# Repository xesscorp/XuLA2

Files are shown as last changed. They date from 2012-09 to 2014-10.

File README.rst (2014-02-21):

==========================================
XuLA2 FPGA Board Repository
==========================================

----------------------------------------------------
Where you'll find *everything* XuLA2-related!
----------------------------------------------------

This repo integrates everything for the XuLA2 FPGA board into one place:

    pcb/:
        Here's where you'll find the schematic and PCB layout stored as Eagle 5 files.
        
    fmw/:
        This contains the firmware for the microcontroller that manages the XuLA2 USB interface.
        
            boot/:
                This is the boot code that manages the reflashing of the uC firmware over the USB link.
                
            user/:
                This is the code that runs during normal operations of the XuLA2 board.
                It manages the interface between the FPGA and the USB link.
                
    FPGA/:
        All the example FPGA designs for the XuLA2 are stored in here.
        (You can find others in the StickIt! repository under the subdirectories
        for the modules they support.)
        
    docs/:
        Look in here for the source of the XuLA2 manual and other supporting documentation.
        
    misc/:
        This is a random, grab-bag of stuff.

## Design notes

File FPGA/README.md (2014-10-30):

==========================================
XuLA2 FPGA Design Examples
==========================================

This directory contains example designs for all models of the XuLA2 board.

Any of the examples can be re-built using the `.xise` file in each directory along
with Xilinx ISE 14.

The following files also allow the examples to be rebuilt using `make`:

`setenv.bat`:
    This sets the PATH to include the Xilinx tools. It's only needed on Windows
    and you'll have to change it depending upon where you have your Xilinx tools
    installed.
    
`makefile`:
    Master makefile that compiles all the design examples for each XuLA2 board model.
    
`fpga_project.mk`:
    The makefile template for each design example. This file is included by the 
    makefile in each design example directory.
    
`fpga_project_rules.mk`:
    The rules for building an FPGA bitstream file from the files in the design
    example directory. This file is used by `fpga_project.mk`.

Really, Really Important Note!!!
------------------------------------------

All of these projects use the new unified library of VHDL components stored in the
[XESS VHDL_Lib repository](https://github.com/xesscorp/VHDL_Lib). If you try to compile 
these projects and you get a bunch of warnings about missing files, then you don't 
have this library installed or it's in the wrong place. Please look in the 
[VHDL_Lib README](https://github.com/xesscorp/VHDL_Lib/blob/master/README.rst) for 
instructions on how to install and use it.

FPGA Design Example Directories
------------------------------------------

`AdcSampler`:
    This example reads samples from a TI ADC108S ADC and stores them in the SDRAM.

`blinker`:
    A simple LED blinker from chapter 4 of the book "FPGAs!? Now What?".

`counter`:
    A simple 26-bit counter that is driven by a 100 MHz clock and whose bits are output
    through the prototyping header. This is a good design to check the functioning of
    the XuLA2 board. *Check the setting for the startup-clock - either JTAGCLK or CCLK -
    to make sure it complies with how you are using the XuLA2 board - either USB-connected
    or standalone.*
    
`EchoTest`:
    A simple design where the FPGA uses the HostIo communication module to receive
    characters from a PC and then echoes them back.
    
`EchoTestVerilog`:
    The same design as `EchoTest` except the top-level module is written in Verilog.

`fast_blinker`:
    The LED blinker design sped-up by using a DCM from chapter 5 of the book "FPGAs!? Now What?".

`fintf_jtag`:
    This design is used by the Python version of XSLOAD when it needs to read or write 
    the contents of the serial flash configuration memory on the XuLA2 board.

`fintf_jtag_old`:
    This design is used by GXSLOAD.EXE when it needs to read or write the contents of the
    serial flash configuration memory on the XuLA2 board.

`hcsr04_test`:
    A simple interface to test an HCSR04 ultrasonic distance measurement module.

`hostio_test`:
    This example tests the ability of the HostIo modules to pass
    data back-and-forth between the FPGA and the host PC.

`HostIoCommTest`:
    This example tests the ability of the HostIo communication module to pass
    data back-and-forth between the FPGA and the host PC.
    
`HostIoToI2cTest`:
    This example allows a host PC to talk to an I2C peripheral.
	
`ramintfc_jtag`:
    This design is used by the Python version of XSLOAD when it needs to read or write 
    the contents of the SDRAM on the XuLA2 board.

`ramintfc_jtag_old`:
    This design is used by GXSLOAD.EXE when it needs to read or write the contents of the
    SDRAM on the XuLA2 board.

`rand_test`:
    This example uses the hostio module to gather samples from a random-number generator module.
    
`RGBLed`:
    This example drives an RGB LED using three pulse-width modulators.
    
`SdcardCtrlTest`:
    This example tests the SD card controller module by having a PC write and read data blocks
    through the USB link.
    
`SdcardSfwTest`:
    This example tests an SD card by having a PC do low-level register reads and writes 
    to the card through the USB link.

`test_board_jtag`:
    This design is used by the Python version of XSTEST to test the SDRAM and report 
    the success or failure through the JTAG and USB links.

`test_board_jtag_old`:
    This design is used by GXSTEST.EXE to test the SDRAM and report the success or failure
    through the JTAG and USB links.

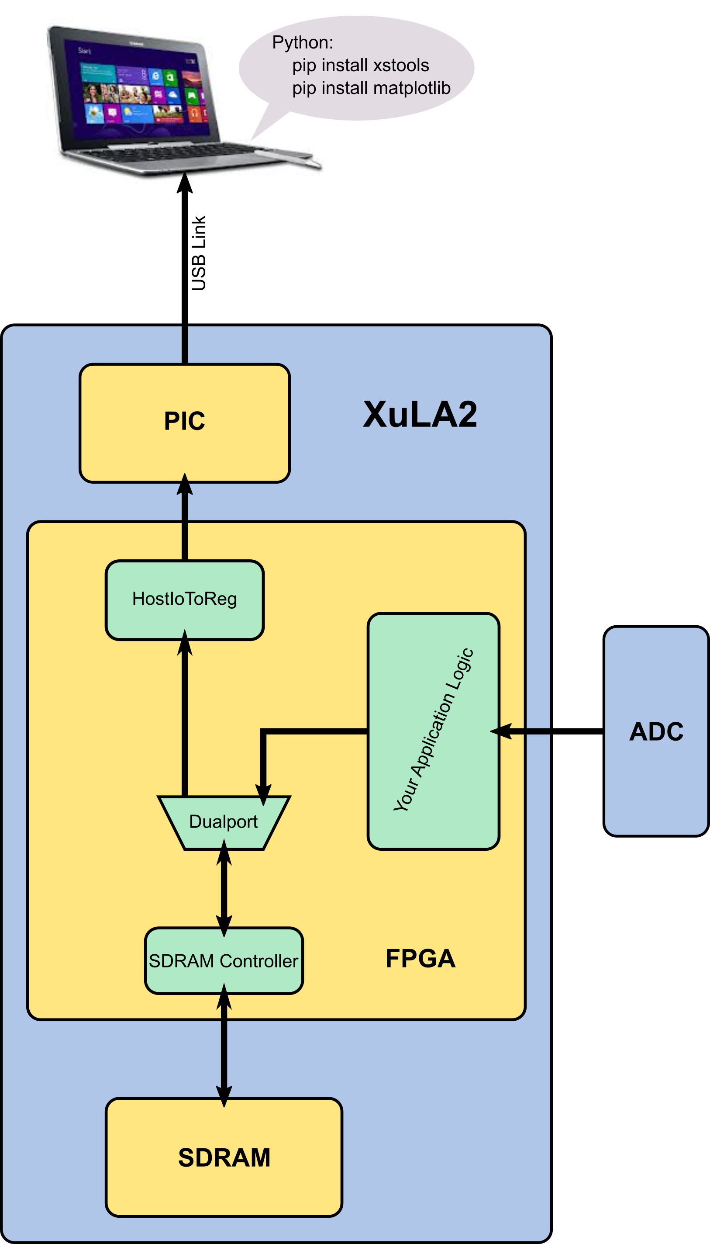
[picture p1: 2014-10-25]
FPGA/AdcSampler/AdcSampler_blockdiag.png

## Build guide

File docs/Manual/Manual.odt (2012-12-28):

How to install, test and use
your new FPGA board

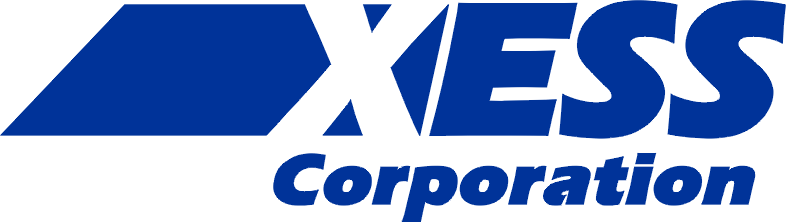
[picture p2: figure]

XESS is disclosing this Document and Intellectual Property (hereinafter “the Design”) to you for use in the development of designs to operate on, or interface with XESS hardware devices. XESS expressly disclaims any liability arising out of the application or use of the Design. XESS reserves the right to make changes, at any time, to the Design as deemed desirable in the sole discretion of XESS. XESS assumes no obligation to correct any errors contained herein or to advise you of any correction if such be made. XESS will not assume any liability for the accuracy or correctness of any engineering or technical support or assistance provided to you in connection with the Design.

THE DESIGN IS PROVIDED “AS IS” WITH ALL FAULTS, AND THE ENTIRE RISK AS TO ITS FUNCTION AND IMPLEMENTATION IS WITH YOU. YOU ACKNOWLEDGE AND AGREE THAT YOU HAVE NOT RELIED ON ANY ORAL OR WRITTEN INFORMATION OR ADVICE, WHETHER GIVEN BY XESS, OR ITS AGENTS OR EMPLOYEES. XESS MAKES NO OTHER WARRANTIES, WHETHER EXPRESS, IMPLIED, OR STATUTORY, REGARDING THE DESIGN, INCLUDING ANY WARRANTIES OF MERCHANTABILITY, FITNESS FOR A PARTICULAR PURPOSE, TITLE, AND NONINFRINGEMENT OF THIRD-PARTY RIGHTS.

IN NO EVENT WILL XESS BE LIABLE FOR ANY CONSEQUENTIAL, INDIRECT, EXEMPLARY, SPECIAL, OR INCIDENTAL DAMAGES, INCLUDING ANY LOST DATA AND LOST PROFITS, ARISING FROM OR RELATING TO YOUR USE OF THE DESIGN, EVEN IF YOU HAVE BEEN ADVISED OF THE POSSIBILITY OF SUCH DAMAGES. THE TOTAL CUMULATIVE LIABILITY OF XESS IN CONNECTION WITH YOUR USE OF THE DESIGN, WHETHER IN CONTRACT OR TORT OR OTHERWISE, WILL IN NO EVENT EXCEED THE AMOUNT OF FEES PAID BY YOU TO XESS HEREUNDER FOR USE OF THE DESIGN. YOU ACKNOWLEDGE THAT THE FEES, IF ANY, REFLECT THE ALLOCATION OF RISK SET FORTH IN THIS AGREEMENT AND THAT XESS WOULD NOT MAKE AVAILABLE THE DESIGN TO YOU WITHOUT THESE LIMITATIONS OF LIABILITY.

The Design is not designed or intended for use in the development of on-line control equipment in hazardous environments requiring fail-safe controls, such as in the operation of nuclear facilities, aircraft navigation or communications systems, air traffic control, life support, or weapons systems (“High-Risk Applications”). XESS specifically disclaims any express or implied warranties of fitness for such High-Risk Applications. You represent that use of the Design in such High-Risk Applications is fully at your risk.

© 2012 XESS, Inc. All rights reserved. XESS, the XESS logo, and other designated brands included herein are trademarks of XESS Corporation. All other trademarks are the property of their respective owners.

This document is licensed under the Attribution-ShareAlike 3.0 Unported license, available at http://creativecommons.org/licenses/by-sa/3.0/.

MAN007 (V1.2) December 28, 2012

The following table shows the revision history for this document.

Date | Version | Revision
07/25/2012 | 0.1 | Pre-release for the XuLA2.
08/1/2012 | 0.2 | Corrected “Spartan-3A” to “Spartan-6”.
08/14/2012 | 1.0 | Changed images for XuLA2 production board. Added instructions for setting FPGA bitstream configuration rate.
08/20/2012 | 1.1 | Added notes about connections from the prototyping header pins to FPGA global clock pins in the Pin Connections appendix.
12/28/2012 | 1.2 | Expanded explanation of how to use a XILINX programming cable with the XuLA2.

# Preliminaries

Here's some helpful information before getting started.

## Getting Help!

Here are some places to get help if you encounter problems:

- If you can't get the XuLA2 hardware to work, send an e-mail message describing your problem to help@xess.com or submit a problem report at http://www.xess.com/help.php. Our web site also has:
  - answers to frequently-asked-questions,
  - example designs, application notes and tutorials for our FPGA boards,
  - a place to sign-up for our email forum where you can post questions to others.
- If you can't get your XILINX ISE WebPACK software tools installed properly, check their web site at http://www.xilinx.com/support/.
- If you need help using the XILINX ISE WebPACK software to create FPGA designs, then check out this tutorial (http://www.xess.com/appnotes/FpgasNowWhatBook.pdf).

## Take Notice!

- The XuLA2 is not 5V-tolerant. Do not connect 5V logic signals to the prototyping header.
- The XuLA2 printed circuit board (PCB) is manufactured such that the terminals of the jumpers labeled "5V", "3.3V" and "1.2V" are connected on the underside of the PCB by short wiring traces. You must cut these traces if you want to open the jumper connections.
- Even if you have experience with the XILINX ISE WebPACK software, please read this section on setting the bitstream generation options for the XuLA2.

# Installation

## Installing the XSTOOLs Utilities and Documentation

XILINX currently provides the free ISE® WebPACKTM software for programming many of their small and mid-size FPGAs and CPLDs. You can download the most current version of ISE WebPACK from www.xilinx.com.

In addition, XESS provides the XSTOOLs utilities for interfacing a PC to your XuLA2. These utilities (along with manuals, design examples and tutorials) are installed automatically when you insert the XSTOOLs CD into your PC. If not, then manually run the SETUP.EXE installation program on the CD. You can also download the XSTOOLs installer from www.xess.com.

## Connecting Your XuLA2 to a PC

The XuLA2 is a USB peripheral that you can attach to any USB 1.1 or 2.0 port through a cable with a five-pin mini-B connector such as this one:

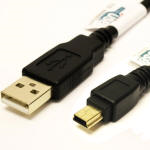
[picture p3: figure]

The LED on your XuLA2 will light up as soon as it establishes a connection with the PC.

## Testing Your XuLA2

Once your XuLA2 is connected to a USB port, you can test it by double-clicking the GXSTEST icon placed on your PC desktop during the XSTOOLs installation. This brings up the window shown below.

Next, select the type of board you are testing and the port that it's attached to. Then click on the TEST button. GXSTEST will configure the FPGA on your XuLA2 to perform a test procedure. Within a few seconds, a status window will appear informing you of the success or failure of the test.

If your XuLA2 fails the test, you will be shown a checklist of common causes for failure. If none of these applies to your situation, then contact XESS Corp (http://www.xess.com/help.php) for further assistance.

## Setting the Jumpers on Your XuLA2

The XuLA2 has three jumpers labeled "5V", "3.3V" and "1.2V" that are used to configure how the board receives power. In their factory-original configuration, the jumpers are unpopulated but the terminals of each jumper are connected on the underside of the PCB by short wiring traces. You must cut these traces if you wish to open the jumper connections. You only need to do this if you are powering your XuLA2 through its prototyping header (not through the USB cable) as described here.

The locations of the shorting traces on the underside of the XuLA2 PCB are shown below.

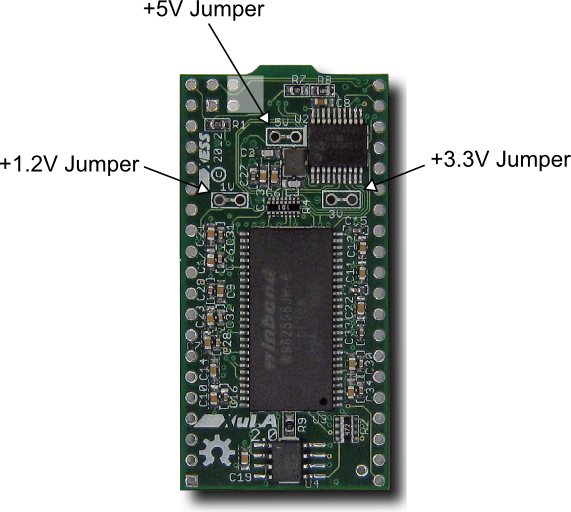
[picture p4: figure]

## Applying Power to Your XuLA2

There are two ways of powering your XuLA2 that can be used alone or in combination:

- receiving power through the USB connector, or
- applying power through the XuLA2 prototyping header.

### Applying Power Through the USB Port

Connecting the XuLA2 to a PC USB port provides a 5V supply capable of delivering up to 500 mA of current. This is sufficient for many small to medium-sized FPGA designs running at less than 200 Mhz.

### Applying Power Through the Prototyping Header

For more power-hungry applications, you can connect one or more voltage supplies directly to the power supply pins of the prototyping header. There are several ways to do this:

- You can attach an 18V–5V supply directly to the 5V pin of the prototyping header. The XuLA2's voltage regulators will generate the required 3.3V and 1.2V supplies needed by the microcontroller, FPGA, SDRAM and Flash (see the figure below). Do not attach a USB cable unless you have removed the shunt from the 5V jumper or else you will short the PC USB supply to the external voltage supply and cause possible damage.
- You can attach a 3.3V supply directly to the 3.3V pin of the prototyping header. This supply will directly power the microcontroller, FPGA I/O, SDRAM and Flash while the voltage regulator will generate the 1.2V needed by the FPGA core logic. Do not attach a USB cable unless you have removed the shunt from the 5V jumper and do not attach a supply to the 5V prototyping pin or else the output of the 3.3V regulator will drive against the external 3.3V supply and cause possible damage.
- You can power the FPGA core logic by attaching a 1.2V supply directly to the 1.2V pin of the prototyping header and then use one of the previous two methods to power the rest of the XuLA2. You must remove the shunt on the 1.2V jumper to isolate the output of the 1.2V regulator from the external 1.2V supply.

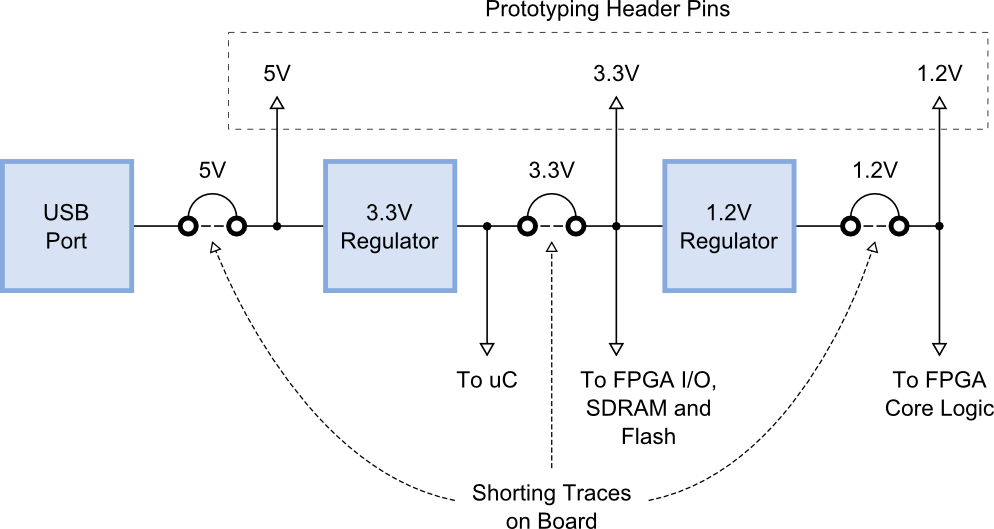
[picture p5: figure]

## Inserting the XuLA2 into a Breadboard

In its factory-original configuration, the XuLA2's prototyping header is empty. If desired, you can solder in a pair of twenty-pin headers and then insert the XuLA2 into a standard solderless breadboard as shown below.

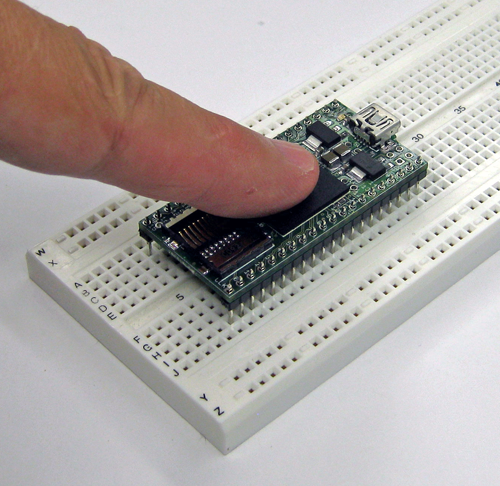
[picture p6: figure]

The XuLA2 PCB will accept common headers with 0.025"-thick pins at 0.1" spacing, but you may find it difficult to remove the XuLA2 given how tightly the breadboard grips the pins. A header with thinner pins (such as the Aries 20-0600-20) is a better choice.

# Programming

This chapter will show you how to download logic designs into the FPGA of your XuLA2 and how to transfer data between the PC and the SDRAM and Flash memories on the board.

## Generating Bitstreams for the FPGA

Before you can download a logic design to the FPGA on your XuLA2, you need to generate a bitstream (i.e., a .BIT file) with XILINX ISE WebPACK. Steps for doing this are given in the XILINX documentation and this XESS tutorial (http://www.xess.com/appnotes/FpgasNowWhatBook.pdf), but there are several details that you have to be aware of when generating the bitstream.

After creating your logic design in ISE WebPACK, right-click on the Generate Programming File item in the Process window and select Process Properties... from the context menu as shown below.

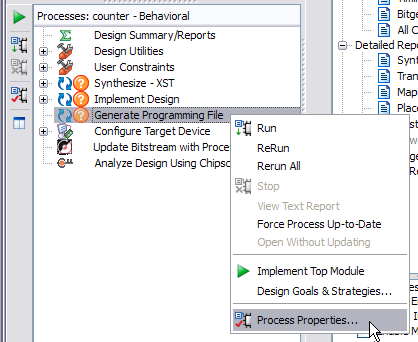
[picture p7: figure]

When the Process Properties window appears, select the Configuration Options category. Make sure the Configuration Pin Done property is set to the value Pull Up. This is necessary for the microcontroller on the XuLA2 to detect when the FPGA has successfully been configured by the bitstream. Also, set the JTAG Pin TCK property to either Float or Pull Down so it does not conflict with the pull-down resistor on the XuLA2. Finally, set the Unused IOB Pins property Float or Pull Up.

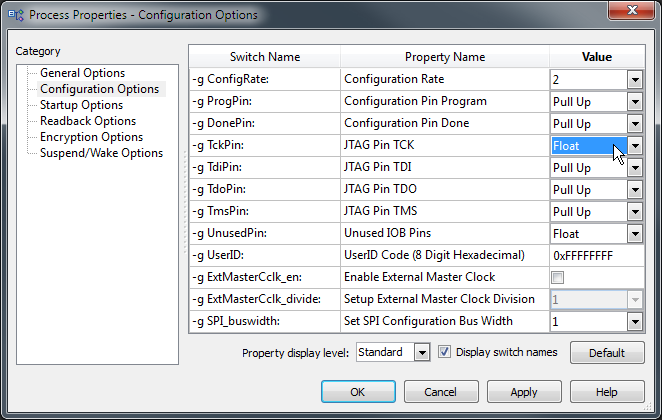
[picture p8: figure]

If you're planning on storing the bitstream into the serial configuration flash, you will also want to set the Configuration Rate to 10 MHz or more. That will ensure the 5 Mbit bitstream will load into the FPGA in ½-second or less. But if you're only going to download the bitstream to the FPGA via the USB link, then the Configuration Rate setting can be ignored.

Finally, select the Startup Options category and set the FPGA Start-Up Clock to one of the following values:

FPGA Start-Up Clock Settings
JTAG Clock | Use this setting when your bitstream will be downloaded directly into the XuLA2's FPGA through the USB cable.
CCLK | Use this setting when your bitstream will be downloaded into the XuLA2's serial configuration Flash for eventual transfer to the FPGA.

Then click OK to finalize your process properties. Now you're ready to generate a bitstream for the XuLA2!

## Downloading Bitstreams into the FPGA

### Downloading Using GXSLOAD

As you work on a logic design, you will usually download the bitstream from the PC to the XuLA2 to test your modifications. The GXSLOAD utility is used for downloading bitstreams over the USB link.

Start GXSLOAD by double-clicking the icon placed on the desktop during the XSTOOLs installation. This brings up the window shown below.

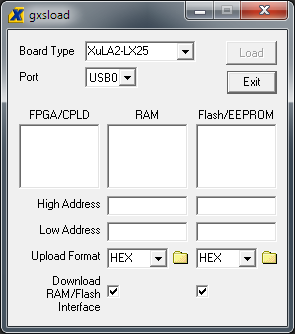
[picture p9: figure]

Now you can download bitstream files to the FPGA or CPLD simply by dragging them from their folder and dropping them into the FPGA/CPLD pane as shown below.

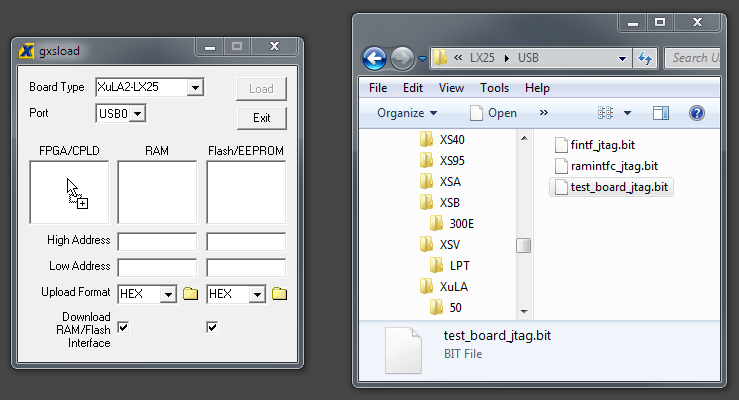
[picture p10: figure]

Once you drop the file, the highlighted file name appears in the FPGA/CPLD pane and the Load button is enabled. Clicking on the Load button will begin sending the bitstream to the XuLA2 through the USB cable. GXSLOAD will reject any non-downloadable files (ones with a suffix other than .BIT). During the downloading process, GXSLOAD will display the name of the bitstream file and the progress of the current download. The LED on the XuLA2 will blink as the bitstream is transferred.

You can drag & drop multiple files into the FPGA/CPLD pane. Clicking your mouse on a file name will highlight the name and select it for downloading. Only one file at a time can be selected for downloading.

Double-clicking the highlighted file will deselect it so no file will be downloaded. Doing this disables the Load button.

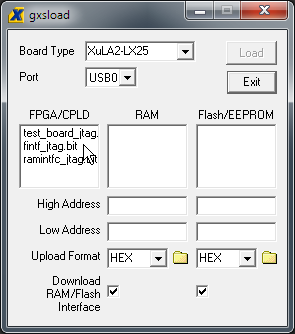
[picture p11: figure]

### Downloading Using a XILINX or Third-Party JTAG Cable

As an alternative to using GXSLOAD and a simple USB cable, you can use a XILINX or third-party JTAG cable to configure the FPGA on the XuLA2. But first, you have to set a non-volatile flag to give priority to the auxiliary JTAG header using the GXSFLAGS utility. Connect the XuLA to your PC with a USB cable and then double-click the GXSFLAGS icon so the following window appears.

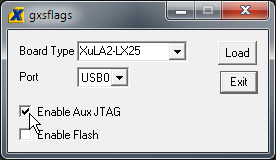
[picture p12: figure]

Click on the Enable Aux JTAG checkbox and then click on the Load button to set the flag. Note that the flag only needs to be set once to support the JTAG cable because it retains its value even when power is removed from the XuLA2. (Be aware that enabling the auxiliary JTAG header disables the functions of the other XSTOOLs utilities such as GXSTEST and GXSLOAD. To restore their functions, you'll have to use GXSFLAGS again to disable the auxiliary JTAG header.)

Now attach your JTAG cable to the auxiliary JTAG header as shown below. (The USB cable remains attached only to provide the XuLA2 with power. You can detach it if the board is getting power from another source, such as through its prototyping header.)

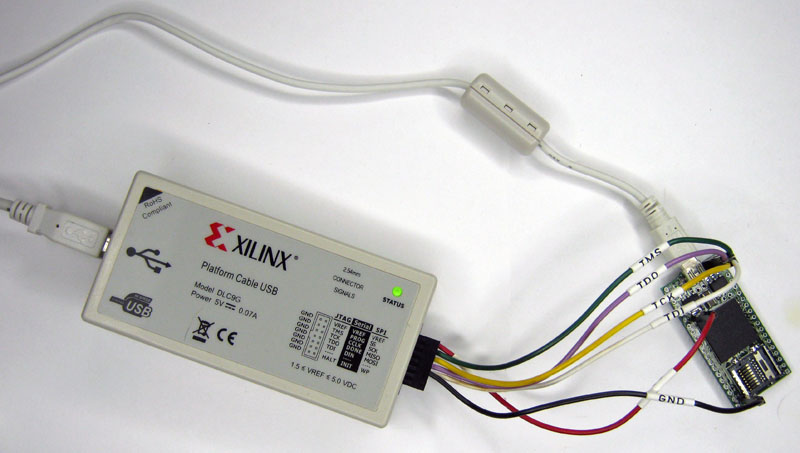
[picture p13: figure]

Here's a close-up of the connections from the XILINX cable to the XuLA2:

Ground Connection Vref Connection To +3.3V JTAG Signal Connections

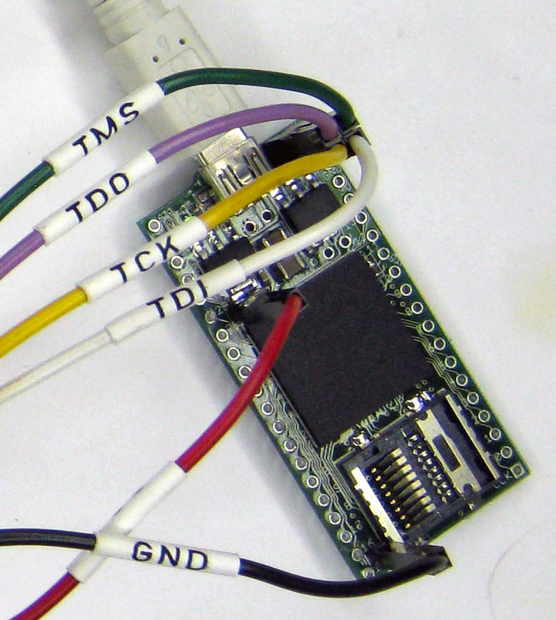
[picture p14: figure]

Now start the ISE WebPACK iMPACT tool and follow the XILINX instructions to download bitstreams to the FPGA in boundary-scan mode.

## Storing Non-Volatile Bitstreams in the Serial Configuration Flash

The FPGA on the XuLA2 stores its configuration in an on-chip SRAM which is erased whenever power is removed. Once you complete a design, you may want to store the bitstream in the serial configuration Flash on the XuLA2. After that, the FPGA will configure itself from the Flash each time power is applied.

Loading a bitstream into the Flash is easy: just drag the .BIT file into the Flash/EEPROM pane of GXSLOAD and click on the Load button. This activates the following sequence of events:

1. The FPGA on the XuLA2 is configured with an interface to transfer data from the USB port to the Flash.
2. The entire Flash is erased.
3. The contents of the .BIT file are downloaded into the Flash through the USB port.

Once the Flash download is completed, the FPGA will be configured with the stored bitstream whenever power is applied to the XuLA2. (Make sure that you selected CCLK as the start-up clock and set the configuration rate to 10 MHz or more when you generated the bitstream or else the FPGA will fail to configure from the Flash.)

You can also use the XILINX iMPACT software to convert FPGA bitstreams into .MCS or .EXO data files. These file types can be programmed into the XuLA2's Flash using GXSLOAD in the same way as with a .BIT file.

Multiple files can be stored in the Flash device just by dragging them into the Flash/EEPROM area, highlighting the files to be downloaded and clicking the Load button. (Note that anything previously stored in the Flash will be erased by each new download.) This is useful if you need to store information in the Flash in addition to the FPGA bitstream. Files are selected and de-selected for downloading just by clicking on their names in the Flash/EEPROM area. The address ranges of the data in each file should not overlap or this will corrupt the data stored in the Flash device!

You can also examine the contents of the Flash by uploading it to the PC. To upload data from an address range in the Flash, type the upper and lower bounds of the range into the High Address and Low Address fields located below the Flash/EEPROM pane, and select the format for the uploaded data from the Upload Format pulldown list. Then click on the file icon () and drag & drop it into any folder.

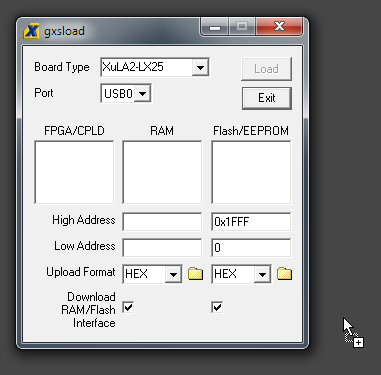
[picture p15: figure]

This activates the following sequence of steps:

1. The FPGA on the XuLA2 is configured with an interface between the Flash device and the PC USB port.
2. The Flash data between the high and low addresses (inclusive) is uploaded through the USB port.
3. The uploaded data is stored in a file named FLSHUPLD with an extension that reflects the selected upload file format.

The uploaded data can be stored in the following formats:

MCS: Intel hexadecimal file format.

HEX: Identical to MCS format.

EXO-16: Motorola S-record format with 16-bit addresses (suitable for 64 KByte uploads only).

EXO-24: Motorola S-record format with 24-bit addresses.

EXO-32: Motorola S-record format with 32-bit addresses.

XESS-16: XESS hexadecimal format with 16-bit addresses. (This is a simplified file format that does not use checksums.)

XESS-24: XESS hexadecimal format with 24-bit addresses.

XESS-32: XESS hexadecimal format with 32-bit addresses.

## Transferring Data to/from the SDRAM

The XuLA2 contains a synchronous DRAM (SDRAM) whose contents can be downloaded and uploaded by GXSLOAD. This is useful for initializing the SDRAM with data for use by the FPGA and then reading the SDRAM contents after the FPGA has operated upon it. The SDRAM is loaded with data by dragging & dropping one or more .EXO, .MCS, .HEX, and/or .XES files into the RAM pane of the gxsload window and then clicking on the Load button. This activates the following sequence of steps:

1. The FPGA is configured with an interface to transfer data between the SDRAM device and the USB port.
2. The contents of the .EXO, .MCS, .HEX or .XES file are downloaded into the SDRAM through the USB port.

You can also examine the contents of the SDRAM device by uploading it to the PC. To upload data from an address range in the SDRAM, type the upper and lower bounds of the range into the High Address and Low Address fields below the RAM pane, and select the format for the uploaded data from the Upload Format pulldown list. Then click on the file icon () and drag & drop it into any folder.

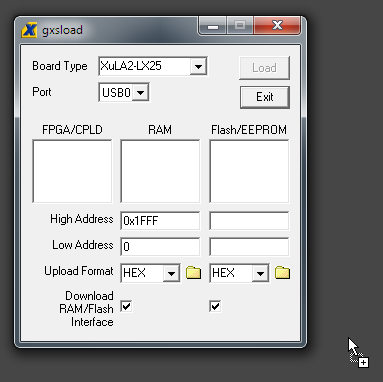
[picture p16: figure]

This activates the following sequence of steps:

1. The FPGA is configured with an interface between the SDRAM device and the PC USB port.
2. The SDRAM data between the high and low addresses (inclusive) is uploaded through the USB port.
3. The uploaded data is stored in a file named RAMUPLD with an extension that reflects the selected upload file format.

The 16-bit data words in the SDRAM are mapped into the eight-bit data format of the .HEX, .MCS, .EXO and .XES files using a Big Endian style. That is, the 16-bit word at location N in the SDRAM is stored in the eight-bit file with the upper eight bits at address 2N and the lower eight bits at address 2N+1. This byte-ordering applies for both RAM uploads and downloads.

# Programmer Models

This section describes the various sections of the XuLA2 and shows how the FPGA I/O is connected to the rest of the circuitry. The schematics which follow are less detailed so as to simplify the descriptions. For more information, you can find a table of pin connections and detailed schematics at the end of this manual.

## XuLA2 Components

The XuLA2 contains the following major components:

FPGA: This is the field programmable gate array.

Microcontroller: The microcontroller (uC) handles initialization, clock generation and USB-to-JTAG communications.

SDRAM: A 256-Mbit SDRAM provides volatile data storage accessible by the FPGA.

SPI Flash: An 8-Mbit serial Flash device provides non-volatile storage for FPGA configuration bitstreams and user data.

MicroSD Card: A Secure Digital memory card provides non-volatile storage for user data.

Prototyping Header: FPGA I/O pins, several uC pins and power/GND pins are connected to this 40-pin header that is meant to mate with solderless breadboards or other devices with 0.1"-spacing sockets.

Aux. JTAG Header: This header provides direct access to the FPGA's JTAG pins.

The interconnection of these components is shown in the following block diagram.

### FPGA

The programmable logic device on the XuLA2 is a XILINX XC6SLX25 Spartan 6 FPGA (http://www.xilinx.com/support/documentation/data_sheets/ds160.pdf) in a 256-ball BGA package (FT256).

### Microcontroller

The XuLA2 uses a Microchip 18F14K50 PIC (http://www.microchip.com/wwwproducts/Devices.aspx?dDocName=en533924) to perform the following functions:

Reset & initialization: Upon power-up or assertion of the reset, the microcontroller initiates the configuration of the FPGA from the SPI Flash and holds the FPGA in its cleared state if the configuration fails. It instantiates its USB endpoints and participates in the USB enumeration process.

Clock generation: The microcontroller uses its pulse-width modulation (PWM) circuitry to generate a 12 MHz square-wave that enters one of the FPGA's global clock inputs.

USB-to-JTAG communication: The microcontroller accepts configuration bitstreams and data as packets over the USB link and transforms these into a sequence of transitions upon the FPGA's JTAG pins. It also receives data from the FPGA through the JTAG port which it bundles into packets for return through the USB link.

### SDRAM

The XuLA2 incorporates a 16M x 16 SDRAM (Winbond W9825G6JH (http://www.winbond.com/hq/enu/ProductAndSales/ProductLines/SpecialtyDRAM/SDRAM/W9825G6JH.htm)) that connects to the FPGA as shown below. To compensate for circuit delays, the clock signal to the SDRAM is re-routed back to a global clock input so the FPGA can synchronize itself with the SDRAM.

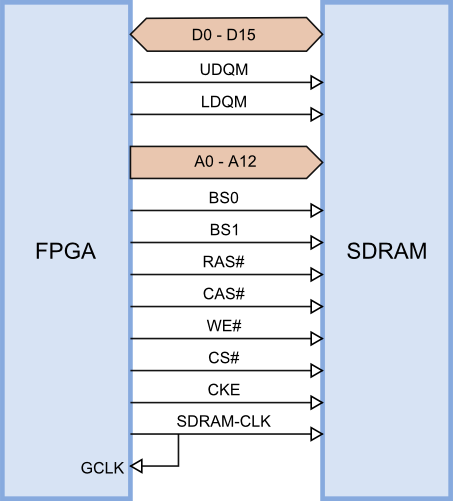
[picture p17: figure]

### SPI Flash and microSD Card

The XuLA2 has an 8-Mbit SPI Flash (Winbond W25Q80BV (http://www.winbond.com/hq/enu/ProductAndSales/ProductLines/FlashMemory/SerialFlash/W25Q80BV.htm)) and a microSD card socket that connect to the FPGA as shown below. During FPGA configuration, the bitstream is read from the SPI flash while the microSD card is disabled. After configuration, either the SPI Flash or the microSD card can be accessed by lowering their respective chip-selects and performing SPI read/write operations.

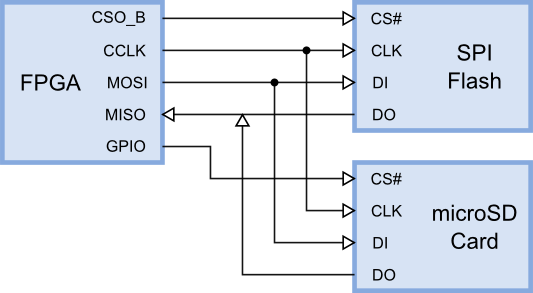
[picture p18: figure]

### Prototyping Header

The prototyping header connects the FPGA I/O, microcontroller I/O and the power/GND planes to external circuitry. The signals attached to the header pins are shown below.

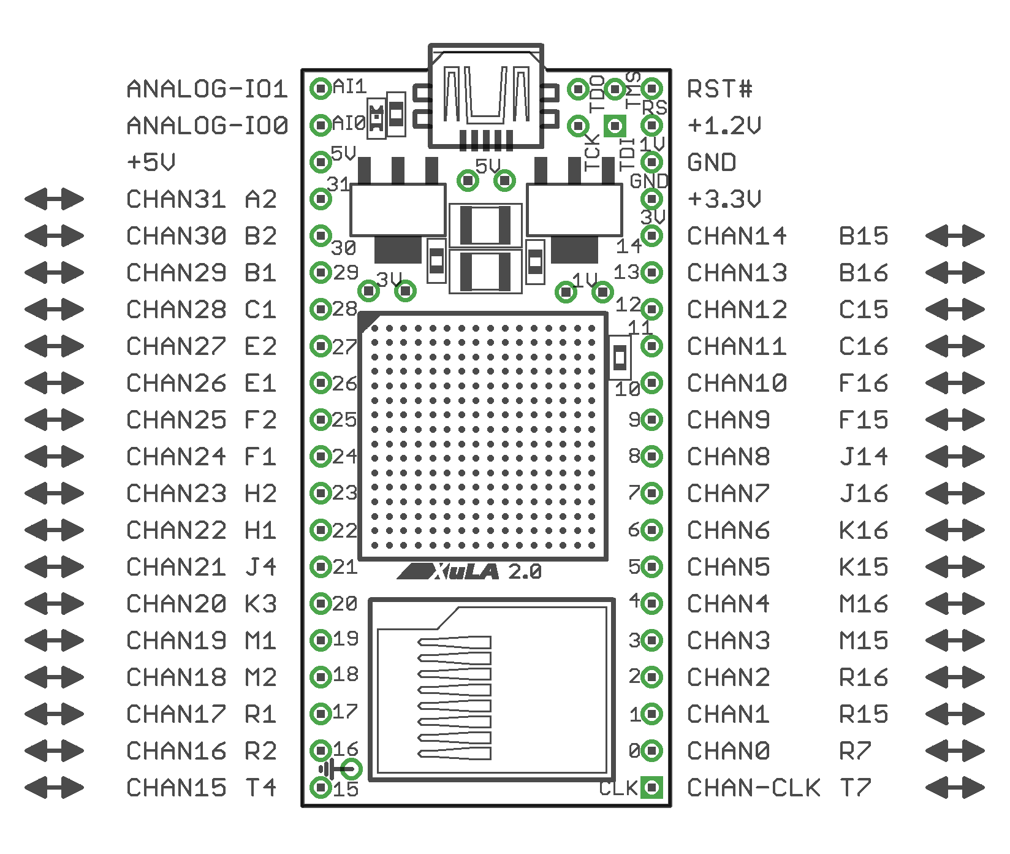
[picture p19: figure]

XuLA2 Header Pin Functions
CHAN0 – CHAN31 | These pins connect directly to the FPGA I/O pins. These pins are not 5V-tolerant (see below).
CHAN-CLK | This is a direct connection to a global clock pin of the FPGA. It can also be used as a general-purpose I/O pin. This pin is not 5V-tolerant (see below).
+5V, +1.2V, +3.3V, GND | These pins connect to the voltage supply planes of the XuLA2 as depicted in this figure.
RST# | This pin connects to the microcontroller reset pin. Pulling it to ground and releasing it will cause the XuLA2 to reconfigure itself.
ANALOG-IO0, ANALOG-IO1 | These pins connect to the analog-to-digital converter in the microcontroller. ANALOG-IO0 can also output an analog voltage with a limited range and precision. Both pins are also useable as standard digital I/O pins.

#### 5V Tolerance Issues

The CHAN* and CHAN-CLK pins connect directly to the pins of the FPGA which typically use an I/O voltage of 3.3V. When driving the inputs of external 5V logic, you should check that their VIH threshold is less than the VOH of the XuLA2 outputs. (This is true for most 5V logic families.)

You must also take care not to exceed the input voltage rating of the FPGA pins when they are driven by external 5V logic outputs. A common technique for protecting the Xilinx FPGA pins is shown below. When presented with a voltage greater than 3.3V + 0.7V = 4.0V, the protection diode built into the FPGA pin's circuitry conducts current and the excess voltage is dropped across the 100Ω resistor. This keeps the voltage directly on the FPGA pin from ever exceeding 4V, which is within tolerated limits. The resistor value should be set so the current through the protection diode does not exceed 10 mA.

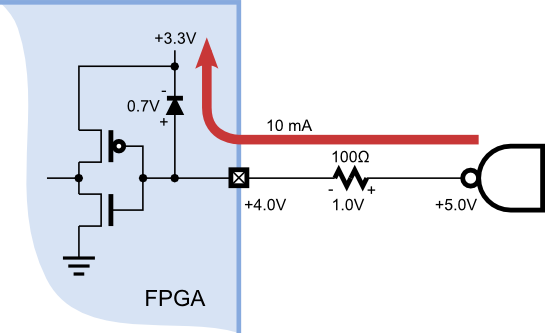
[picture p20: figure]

However, by default, the Xilinx Spartan-6 FPGA disables the protection diodes. In order to enable these diodes, you can place the following text into your Xilinx ISE project constraint file for every I/O pin that will be connected to 5V logic:

NET "input_name" IOSTANDARD = PCI66_3;

Or you can use the Xilinx PlanAhead tool to set the I/O standard for the pins like so:

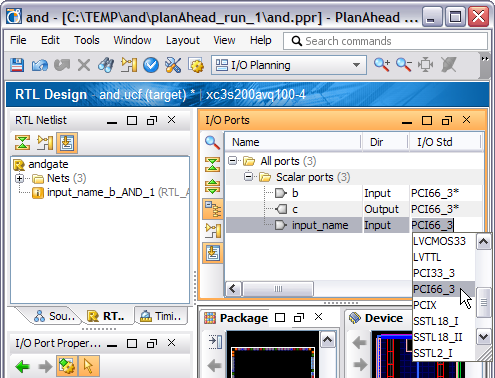
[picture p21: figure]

### Auxiliary JTAG Header

This four-pin header (shown below) provides third-party JTAG cables with access to the JTAG pins of the FPGA.

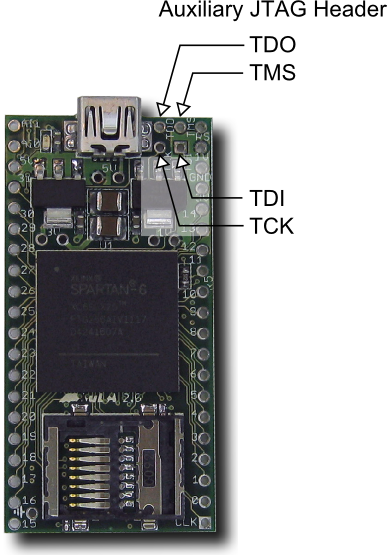
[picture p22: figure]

The connections of the JTAG header to the rest of the XuLA2 circuitry are as follows.

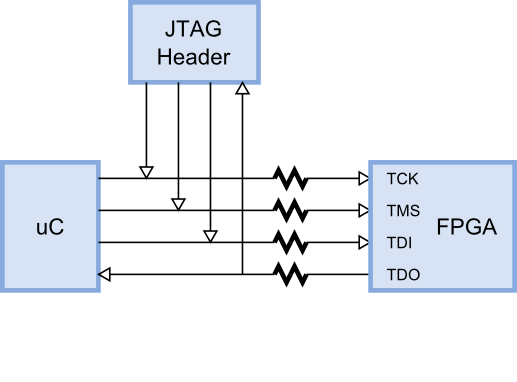
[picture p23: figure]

The current limiting resistors prevent the microcontroller or JTAG cable from damaging the FPGA if they are using a higher supply voltage than the FPGA.

When using a third-party JTAG cable, the associated I/O pins of the microcontroller must be placed in a high-impedance state. The procedure for doing this is described here.

# Pin Connections

Net Name | FPGA | SDRAM | Prototyping Header | SPI Flash | microSD | uC | Notes
A0 | E4 | A0
A1 | E3 | A1
A2 | D3 | A2
A3 | C3 | A3
A4 | B12 | A4
A5 | A12 | A5
A6 | D12 | A6
A7 | E12 | A7
A8 | G16 | A8
A9 | G12 | A9
A10 | F4 | A10
A11 | G11 | A11
A12 | H13 | A12
BS0 | H3 | BS0
BS1 | G3 | BS1
CAS# | L3 | CAS#
CHAN-CLK | T7 | | CHAN-CLK | | | | Goes to FPGA GCLK pin.
CHAN0 | R7 | | CHAN0 | | | | Goes to FPGA GCLK pin.
CHAN1 | R15 | | CHAN1
CHAN2 | R16 | | CHAN2
CHAN3 | M15 | | CHAN3
CHAN4 | M16 | | CHAN4
CHAN5 | K15 | | CHAN5
CHAN6 | K16 | | CHAN6
CHAN7 | J16 | | CHAN7 | | | | Goes to FPGA GCLK pin.
CHAN8 | J14 | | CHAN8 | | | | Goes to FPGA GCLK pin.
CHAN9 | F15 | | CHAN9
CHAN10 | F16 | | CHAN10
CHAN11 | C16 | | CHAN11
CHAN12 | C15 | | CHAN12
CHAN13 | B16 | | CHAN13
CHAN14 | B15 | | CHAN14
CHAN15 | T4 | | CHAN15
CHAN16 | R2 | | CHAN16
CHAN17 | R1 | | CHAN17
CHAN18 | M2 | | CHAN18
CHAN19 | M1 | | CHAN19
CHAN20 | K3 | | CHAN20 | | | | Goes to FPGA GCLK pin.
CHAN21 | J4 | | CHAN21 | | | | Goes to FPGA GCLK pin.
CHAN22 | H1 | | CHAN22
CHAN23 | H2 | | CHAN23
CHAN24 | F1 | | CHAN24 | | | | Goes to FPGA GCLK pin.
CHAN25 | F2 | | CHAN25 | | | | Goes to FPGA GCLK pin.
CHAN26 | E1 | | CHAN26
CHAN27 | E2 | | CHAN27
CHAN28 | C1 | | CHAN28
CHAN29 | B1 | | CHAN29
CHAN30 | B2 | | CHAN30
CHAN31 | A2 | | CHAN31
CKE | J12 | CKE
D0 | P6 | D0
D1 | T6 | D1
D2 | T5 | D2
D3 | P5 | D3
D4 | R5 | D4
D5 | N5 | D5
D6 | P4 | D6
D7 | N4 | D7
D8 | P12 | D8
D9 | R12 | D9
D10 | T13 | D10
D11 | T14 | D11
D12 | R14 | D12
D13 | T15 | D13
D14 | T12 | D14
D15 | P11 | D15
FLASH-CS# | T3 | | | CS# | | | SPI Flash chip-select.
FPGA-CCLK | R11 | | | SCLK | SCLK
FPGA-CLK | A9 | | | | | I/O | 12 MHz from uC.
FPGA-DONE | P13 | | | | | I/O
FPGA-MISO | P10 | | | DO | DO
FPGA-MOSI | T10 | | | DI | DI
FPGA-PROG_B | T2 | | | | | I/O
FPGA-TCK | C14 | | | | | I/O
FPGA-TDI | C12 | | | | | I/O
FPGA-TDO | E14 | | | | | I/O
FPGA-TMS | A15 | | | | | I/O
LDQM | M4 | LDQM
RAS# | L4 | RAS#
SD-CS# | T8 | | | | CS# | | MicroSD chip-select.
SDRAM-CLK | K12 | CLK
SDRAM_CLKFB | K11 | | | | | | SDRAM clock feedback.
SDRAM-CS# | H4 | CS#
UDQM | L13 | UDQM
WE# | M3 | WE#

# Schematic

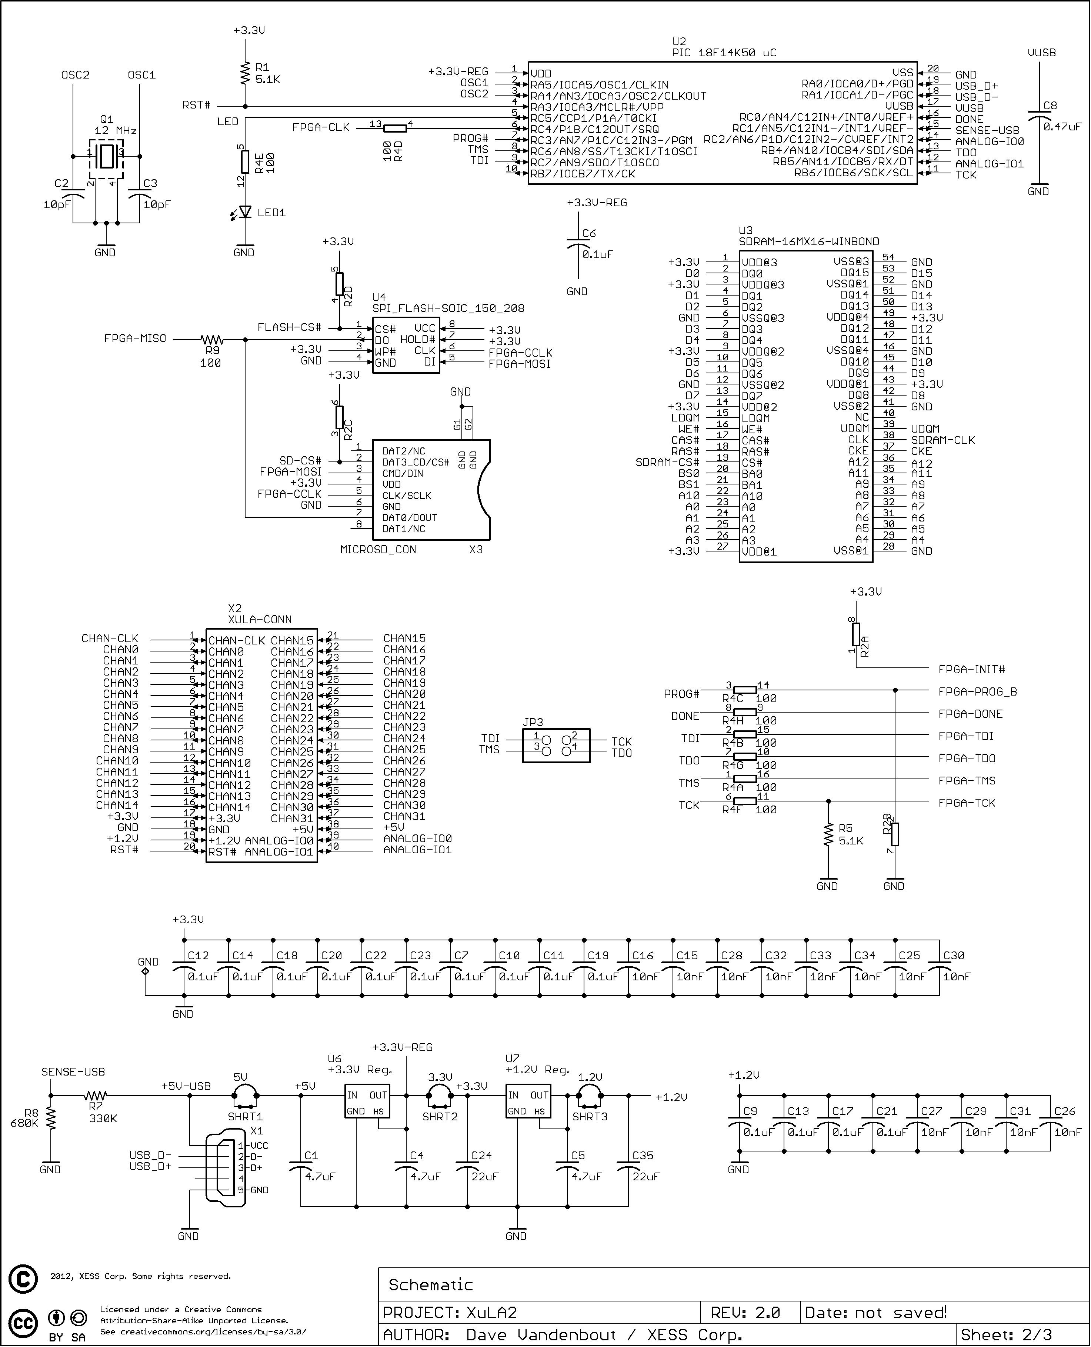
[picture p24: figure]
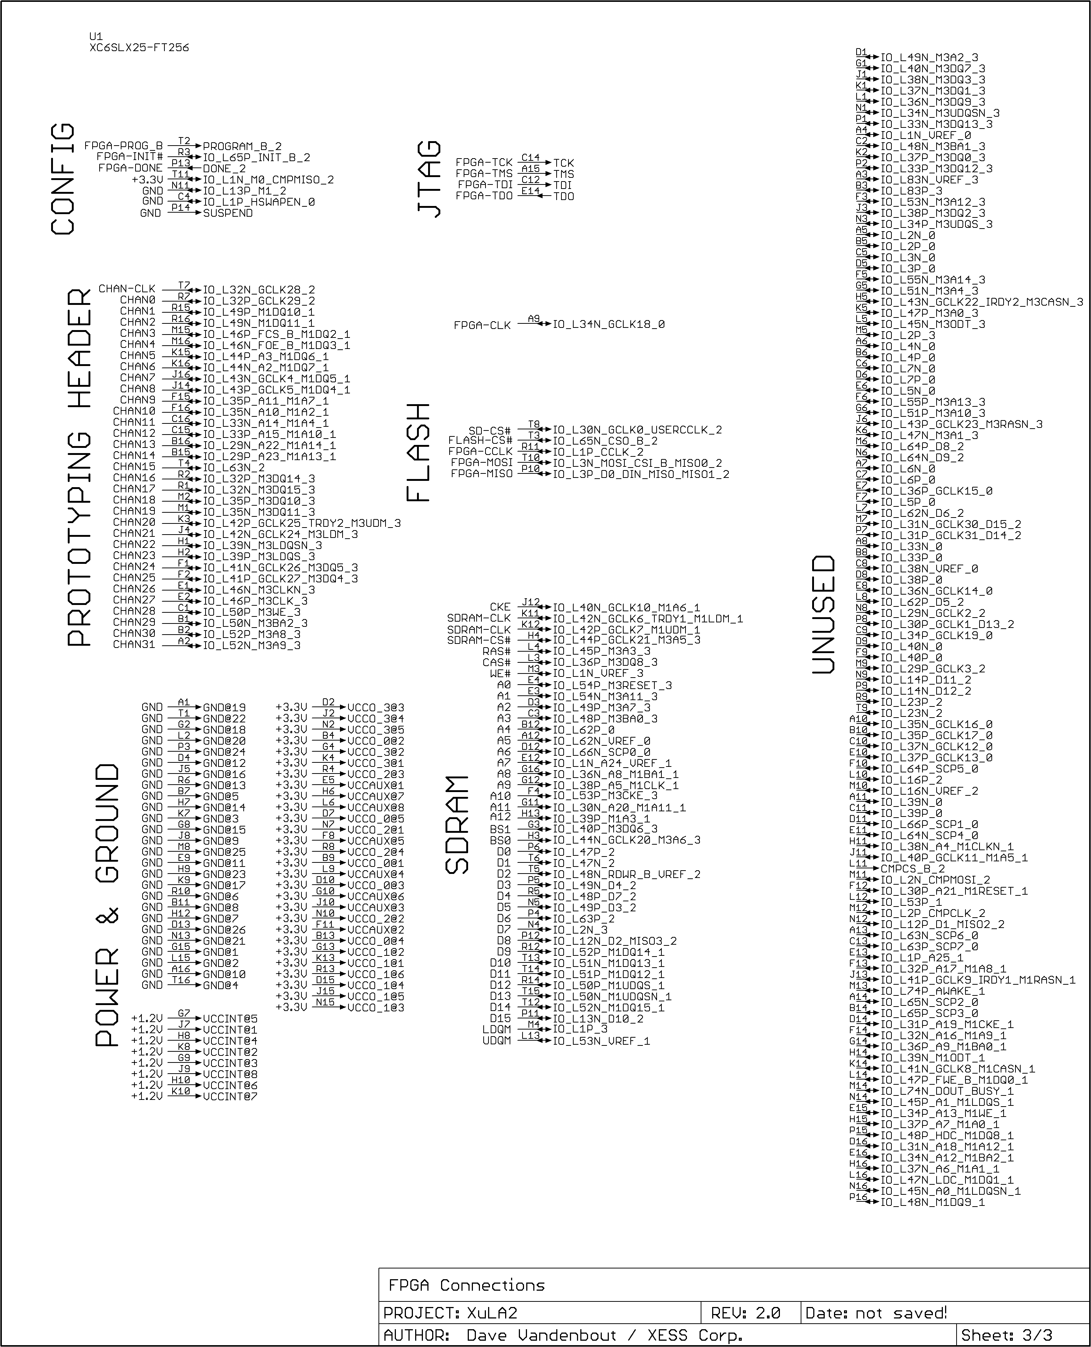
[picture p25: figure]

Pin Connections

www.xess.com 24 MAN007 (V1.2) Dec 28, 2012

www.xess.com 25 MAN007 (V1.2) Dec 28, 2012

MAN007 (V1.2) Dec 28, 2012

Table of Contents

MAN007 (V1.2) Dec 28, 2012 www.xess.com

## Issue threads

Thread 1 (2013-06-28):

Linux on XuLA2?

lollisoft, 2013-06-28:
Are there any hints or attempts for Linux on XuLA2?

I've read something about the toolchain and a kernel. So it may be a starting point.

Before I buy such a board, I like to know if Linux can be made running on this board.

Thanks, Lothar

tommythorn, 2015-07-03:
Is this still an issue?  I'm using my XuLA2-lx25 exclusively from both Linux and Mac OS X, the latter requires running ISE in a Linux VM but the XSTOOLs runs natively under either.

lollisoft, 2015-07-07:
Yes,

I am generally interested into running linux on that device. Do you have more informations / a working design?

Thanks, Lothar

Am 03.07.2015 um 20:23 schrieb Tommy Thorn:

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

tommythorn, 2015-07-07:
Sorry, I misunderstood.  I don't have Linux running yet, but my YARVI will evolve to support the supervisor spec and thus boot Linux.  You may have luck getting Microblaze or OpenRISC going.

Closed 2021-03-07.

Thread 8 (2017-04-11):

xula2 on windows 10 driver problem

cambazz, 2017-04-11:
Hello,

When I try to install the driver for the xula2 board (by going to hardware manager, right clicking on the xula board, and selecting "update driver software", windows gives the following error:

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

Any ideas how I can fix this problem?

Best regards,
C.

xesscorp, 2017-04-11:
The XuLA2 uses the libusb-win32 driver. The installer should install this, but some people need to do it manually. Here are the instructions for doing that:

The XSTOOLs installer places a utility called zadig.exe in the C:\Programs (x86)\XSTOOLs\libusb-win32 directory. Once you have the XSTOOLs installed, run the zadig.exe program and then plug in your XSUSB board. Then just 1) select the libusb-win32 driver and 2) click on the Install Driver button. Then the driver should be installed.

cambazz, 2017-04-12:
Hello, I managed to install the driver, but none of the programs will start. For example the test program. I tried executing from command line, and it will give no error, and no output.

Any ideas?

Best regards,
C.

Bharatcs, 2020-05-21:
Same problem in win 10 ,even after installing ibusb-win32 driver. None of the program will start.

Closed 2021-03-07.

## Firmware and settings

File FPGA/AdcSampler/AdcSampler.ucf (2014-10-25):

#**********************************************************************
# Copyright (c) 1997-2014 by XESS Corp <http://www.xess.com>.
# All rights reserved.
#
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
# You should have received a copy of the GNU Lesser General Public
# License along with this library.  If not, see 
# <http://www.gnu.org/licenses/>.
#**********************************************************************

NET fpgaClk_i      LOC = A9;    # 12 MHz clock input.

##############################
# SDRAM
##############################
NET sdCke_o        LOC = J12;
NET sdClk_o        LOC = K11;
NET sdClkFb_i      LOC = K12;
NET sdCe_bo        LOC = H4;
NET sdRas_bo       LOC = L4;
NET sdCas_bo       LOC = L3;
NET sdWe_bo        LOC = M3;
NET sdDqml_o       LOC = M4;
NET sdDqmh_o       LOC = L13;
NET sdBs_o<0>      LOC = H3;
NET sdBs_o<1>      LOC = G3;
NET sdAddr_o<0>    LOC = E4;
NET sdAddr_o<1>    LOC = E3;
NET sdAddr_o<2>    LOC = D3;
NET sdAddr_o<3>    LOC = C3;
NET sdAddr_o<4>    LOC = B12;
NET sdAddr_o<5>    LOC = A12;
NET sdAddr_o<6>    LOC = D12;
NET sdAddr_o<7>    LOC = E12;
NET sdAddr_o<8>    LOC = G16;
NET sdAddr_o<9>    LOC = G12;
NET sdAddr_o<10>   LOC = F4;
NET sdAddr_o<11>   LOC = G11;
NET sdAddr_o<12>   LOC = H13;
NET sdData_io<0>   LOC = P6;
NET sdData_io<1>   LOC = T6;
NET sdData_io<2>   LOC = T5;
NET sdData_io<3>   LOC = P5;
NET sdData_io<4>   LOC = R5;
NET sdData_io<5>   LOC = N5;
NET sdData_io<6>   LOC = P4;
NET sdData_io<7>   LOC = N4;
NET sdData_io<8>   LOC = P12;
NET sdData_io<9>   LOC = R12;
NET sdData_io<10>  LOC = T13;
NET sdData_io<11>  LOC = T14;
NET sdData_io<12>  LOC = R14;
NET sdData_io<13>  LOC = T15;
NET sdData_io<14>  LOC = T12;
NET sdData_io<15>  LOC = P11;

##############################
# ADC
##############################
#FIX THESE PIN ASSIGNMENTS!!!!
NET cs_bo          LOC = T3;
NET sclk_o         LOC = R11;
NET mosi_o         LOC = T10;
NET miso_i         LOC = P10;

##############################
# I/O Drive
##############################
NET fpgaClk_i      IOSTANDARD = LVTTL;
NET sdClk_o        IOSTANDARD = LVTTL | SLEW=FAST | DRIVE=8;
NET sdClkFb_i      IOSTANDARD = LVTTL;
net sdCke_o        IOSTANDARD = LVTTL;
net sdCe_bo        IOSTANDARD = LVTTL;
NET sdAddr_o*      IOSTANDARD = LVTTL | SLEW=SLOW | DRIVE=6;
NET sdBs_o*        IOSTANDARD = LVTTL | SLEW=SLOW | DRIVE=6;
NET sdRas_bo       IOSTANDARD = LVTTL | SLEW=SLOW | DRIVE=6;
NET sdCas_bo       IOSTANDARD = LVTTL | SLEW=SLOW | DRIVE=6;
NET sdWe_bo        IOSTANDARD = LVTTL | SLEW=SLOW | DRIVE=6;
NET sdData_io*     IOSTANDARD = LVTTL | SLEW=SLOW | DRIVE=6;
NET sdDqmh_o       IOSTANDARD = LVTTL | SLEW=SLOW | DRIVE=6;
NET sdDqml_o       IOSTANDARD = LVTTL | SLEW=SLOW | DRIVE=6;
NET cs_bo          IOSTANDARD = LVTTL;
NET sclk_o         IOSTANDARD = LVTTL;
NET miso_i         IOSTANDARD = LVTTL;
NET mosi_o         IOSTANDARD = LVTTL;

##############################
# Clock Nets
##############################
NET "fpgaClk_i" TNM_NET = "fpgaClk_i";
TIMESPEC "TSfpgaClk_i" = PERIOD "fpgaClk_i" 12 MHz HIGH 50%;

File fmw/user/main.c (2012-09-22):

//*********************************************************************
// Copyright (C) 2010 Dave Vanden Bout / XESS Corp. / www.xess.com
//
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
//====================================================================
//
// Module Description:
//  This module boots up the USB-to-JTAG firmware.  Look in user.c
//  for the code that does the majority of the work.
//
//********************************************************************

#include "USB/usb.h"
#include "USB/usb_function_generic.h"
#include "HardwareProfile.h"
#include "user.h"
#include "Blinker.h"

static void InitializeSystem( void );
void USBDeviceTasks( void );
void YourHighPriorityISRCode( void );
void YourLowPriorityISRCode( void );
void USBCBInitEP( void ); // This callback function was moved to user.c.

/** VECTOR REMAPPING *******************************************/
#define REMAPPED_RESET_VECTOR_ADDRESS 0x800
#define REMAPPED_HIGH_INTERRUPT_VECTOR_ADDRESS 0x808
#define REMAPPED_LOW_INTERRUPT_VECTOR_ADDRESS 0x818

#pragma code REMAPPED_RESET_VECTOR = REMAPPED_RESET_VECTOR_ADDRESS
extern void _startup( void );        // See c018i.c in your C18 compiler dir
void _reset( void )
{
    _asm goto _startup _endasm
}



#pragma code
#pragma interrupt YourHighPriorityISRCode
void YourHighPriorityISRCode()
{
    //Check which interrupt flag caused the interrupt.
    //Service the interrupt
    //Clear the interrupt flag
    //Etc.
    #if defined( USB_INTERRUPT )
    USBDeviceTasks();
    #endif
}   //This return will be a "retfie fast", since this is in a #pragma interrupt section



#pragma code REMAPPED_HIGH_INTERRUPT_VECTOR = REMAPPED_HIGH_INTERRUPT_VECTOR_ADDRESS
void Remapped_High_ISR( void )
{
    _asm goto YourHighPriorityISRCode _endasm
}



#pragma code
#pragma interruptlow YourLowPriorityISRCode
void YourLowPriorityISRCode()
{
    Blinker();
}   //This return will be a "retfie fast", since this is in a #pragma interrupt section



#pragma code REMAPPED_LOW_INTERRUPT_VECTOR = REMAPPED_LOW_INTERRUPT_VECTOR_ADDRESS
void Remapped_Low_ISR( void )
{
    _asm goto YourLowPriorityISRCode _endasm
}



#pragma code

void main( void )
{
    InitializeSystem();

    #if defined( USB_INTERRUPT )
    USBDeviceAttach();
    #endif

    while ( 1 )
    {
        #if defined( USB_POLLING )
        // Check bus status and service USB interrupts.
        USBDeviceTasks(); // Call every 100us or so (takes ~50 instruction cycles before it returns).
        #endif

        ProcessIO();
    }
}



static void InitializeSystem( void )
{
    UserInit();
    USBDeviceInit();
}



// ******************************************************************************************************
// ************** USB Callback Functions ****************************************************************
// ******************************************************************************************************
// The USB firmware stack will call the callback functions USBCBxxx() in response to certain USB related
// events.  For example, if the host PC is powering down, it will stop sending out Start of Frame (SOF)
// packets to your device.  In response to this, all USB devices are supposed to decrease their power
// consumption from the USB Vbus to <2.5mA each.  The USB module detects this condition (which according
// to the USB specifications is 3+ms of no bus activity/SOF packets) and then calls the USBCBSuspend()
// function.  You should modify these callback functions to take appropriate actions for each of these
// conditions.  For example, in the USBCBSuspend(), you may wish to add code that will decrease power
// consumption from Vbus to <2.5mA (such as by clock switching, turning off LEDs, putting the
// microcontroller to sleep, etc.).  Then, in the USBCBWakeFromSuspend() function, you may then wish to
// add code that undoes the power saving things done in the USBCBSuspend() function.

// The USBCBSendResume() function is special, in that the USB stack will not automatically call this
// function.  This function is meant to be called from the application firmware instead.  See the
// additional comments near the function.

/******************************************************************************
 * Function:        void USBCBSuspend(void)
 *
 * PreCondition:    None
 *
 * Input:           None
 *
 * Output:          None
 *
 * Side Effects:    None
 *
 * Overview:        Call back that is invoked when a USB suspend is detected
 *
 * Note:            None
 *****************************************************************************/
void USBCBSuspend( void )
{
    //Example power saving code.  Insert appropriate code here for the desired
    //application behavior.  If the microcontroller will be put to sleep, a
    //process similar to that shown below may be used:

    //ConfigureIOPinsForLowPower();
    //SaveStateOfAllInterruptEnableBits();
    //DisableAllInterruptEnableBits();
    //EnableOnlyTheInterruptsWhichWillBeUsedToWakeTheMicro();	//should enable at least USBActivityIF as a wake source
    //Sleep();
    //RestoreStateOfAllPreviouslySavedInterruptEnableBits();	//Preferrably, this should be done in the USBCBWakeFromSuspend() function instead.
    //RestoreIOPinsToNormal();									//Preferrably, this should be done in the USBCBWakeFromSuspend() function instead.

    //IMPORTANT NOTE: Do not clear the USBActivityIF (ACTVIF) bit here.  This bit is
    //cleared inside the usb_device.c file.  Clearing USBActivityIF here will cause
    //things to not work as intended.


    #if defined( __C30__ )
    #if 0
    U1EIR              = 0xFFFF;
    U1IR               = 0xFFFF;
    U1OTGIR            = 0xFFFF;
    IFS5bits.USB1IF    = 0;
    IEC5bits.USB1IE    = 1;
    U1OTGIEbits.ACTVIE = 1;
    U1OTGIRbits.ACTVIF = 1;
    Sleep();
    #endif
    #endif
} /* USBCBSuspend */



/******************************************************************************
 * Function:        void _USB1Interrupt(void)
 *
 * PreCondition:    None
 *
 * Input:           None
 *
 * Output:          None
 *
 * Side Effects:    None
 *
 * Overview:        This function is called when the USB interrupt bit is set
 *					In this example the interrupt is only used when the device
 *					goes to sleep when it receives a USB suspend command
 *
 * Note:            None
 *****************************************************************************/
#if 0
void __attribute__ ( ( interrupt ) ) _USB1Interrupt( void )
{
    #if !defined( self_powered )
    if ( U1OTGIRbits.ACTVIF )
    {
        IEC5bits.USB1IE    = 0;
        U1OTGIEbits.ACTVIE = 0;
        IFS5bits.USB1IF    = 0;

        //USBClearInterruptFlag(USBActivityIFReg,USBActivityIFBitNum);
        USBClearInterruptFlag( USBIdleIFReg, USBIdleIFBitNum );
        //USBSuspendControl = 0;
    }
    #endif
}



#endif

/******************************************************************************
 * Function:        void USBCBWakeFromSuspend(void)
 *
 * PreCondition:    None
 *
 * Input:           None
 *
 * Output:          None
 *
 * Side Effects:    None
 *
 * Overview:        The host may put USB peripheral devices in low power
 *					suspend mode (by "sending" 3+ms of idle).  Once in suspend
 *					mode, the host may wake the device back up by sending non-
 *					idle state signalling.
 *
 *					This call back is invoked when a wakeup from USB suspend
 *					is detected.
 *
 * Note:            None
 *****************************************************************************/
void USBCBWakeFromSuspend( void )
{
    // If clock switching or other power savings measures were taken when
    // executing the USBCBSuspend() function, now would be a good time to
    // switch back to normal full power run mode conditions.  The host allows
    // a few milliseconds of wakeup time, after which the device must be
    // fully back to normal, and capable of receiving and processing USB
    // packets.  In order to do this, the USB module must receive proper
    // clocking (IE: 48MHz clock must be available to SIE for full speed USB
    // operation).
}



/********************************************************************
 * Function:        void USBCB_SOF_Handler(void)
 *
 * PreCondition:    None
 *
 * Input:           None
 *
 * Output:          None
 *
 * Side Effects:    None
 *
 * Overview:        The USB host sends out a SOF packet to full-speed
 *                  devices every 1 ms. This interrupt may be useful
 *                  for isochronous pipes. End designers should
 *                  implement callback routine as necessary.
 *
 * Note:            None
 *******************************************************************/
void USBCB_SOF_Handler( void )
{
    // No need to clear UIRbits.SOFIF to 0 here.
    // Callback caller is already doing that.
}



/*******************************************************************
* Function:        void USBCBErrorHandler(void)
*
* PreCondition:    None
*
* Input:           None
*
* Output:          None
*
* Side Effects:    None
*
* Overview:        The purpose of this callback is mainly for
*                  debugging during development. Check UEIR to see
*                  which error causes the interrupt.
*
* Note:            None
*******************************************************************/
void USBCBErrorHandler( void )
{
    // No need to clear UEIR to 0 here.
    // Callback caller is already doing that.

    // Typically, user firmware does not need to do anything special
    // if a USB error occurs.  For example, if the host sends an OUT
    // packet to your device, but the packet gets corrupted (ex:
    // because of a bad connection, or the user unplugs the
    // USB cable during the transmission) this will typically set
    // one or more USB error interrupt flags.  Nothing specific
    // needs to be done however, since the SIE will automatically
    // send a "NAK" packet to the host.  In response to this, the
    // host will normally retry to send the packet again, and no
    // data loss occurs.  The system will typically recover
    // automatically, without the need for application firmware
    // intervention.

    // Nevertheless, this callback function is provided, such as
    // for debugging purposes.
}



/*******************************************************************
 * Function:        void USBCBCheckOtherReq(void)
 *
 * PreCondition:    None
 *
 * Input:           None
 *
 * Output:          None
 *
 * Side Effects:    None
 *
 * Overview:        When SETUP packets arrive from the host, some
 *                  firmware must process the request and respond
 *					appropriately to fulfill the request.  Some of
 *					the SETUP packets will be for standard
 *					USB "chapter 9" (as in, fulfilling chapter 9 of
 *					the official USB specifications) requests, while
 *					others may be specific to the USB device class
 *					that is being implemented.  For example, a HID
 *					class device needs to be able to respond to
 *					"GET REPORT" type of requests.  This
 *					is not a standard USB chapter 9 request, and
 *					therefore not handled by usb_device.c.  Instead
 *					this request should be handled by class specific
 *					firmware, such as that contained in usb_function_hid.c.
 *
 * Note:            None
 *****************************************************************************/
void USBCBCheckOtherReq( void )
{
} //end



/*******************************************************************
 * Function:        void USBCBStdSetDscHandler(void)
 *
 * PreCondition:    None
 *
 * Input:           None
 *
 * Output:          None
 *
 * Side Effects:    None
 *
 * Overview:        The USBCBStdSetDscHandler() callback function is
 *					called when a SETUP, bRequest: SET_DESCRIPTOR request
 *					arrives.  Typically SET_DESCRIPTOR requests are
 *					not used in most applications, and it is
 *					optional to support this type of request.
 *
 * Note:            None
 *****************************************************************************/
void USBCBStdSetDscHandler( void )
{
    // Must claim session ownership if supporting this request
} //end



/******************************************************************************
 * Function:        void USBCBInitEP(void)
 *
 * PreCondition:    None
 *
 * Input:           None
 *
 * Output:          None
 *
 * Side Effects:    None
 *
 * Overview:        This function is called when the device becomes
 *                  initialized, which occurs after the host sends a
 *                  SET_CONFIGURATION (wValue not = 0) request.  This
 *					callback function should initialize the endpoints
 *					for the device's usage according to the current
 *					configuration.
 *
 * Note:            None
 *****************************************************************************/
// This callback function was moved to user.c.


/********************************************************************
 * Function:        void USBCBSendResume(void)
 *
 * PreCondition:    None
 *
 * Input:           None
 *
 * Output:          None
 *
 * Side Effects:    None
 *
 * Overview:        The USB specifications allow some types of USB
 *                  peripheral devices to wake up a host PC (such
 *					as if it is in a low power suspend to RAM state).
 *					This can be a very useful feature in some
 *					USB applications, such as an Infrared remote
 *					control	receiver.  If a user presses the "power"
 *					button on a remote control, it is nice that the
 *					IR receiver can detect this signalling, and then
 *					send a USB "command" to the PC to wake up.
 *
 *					The USBCBSendResume() "callback" function is used
 *					to send this special USB signalling which wakes
 *					up the PC.  This function may be called by
 *					application firmware to wake up the PC.  This
 *					function should only be called when:
 *
 *					1.  The USB driver used on the host PC supports
 *						the remote wakeup capability.
 *					2.  The USB configuration descriptor indicates
 *						the device is remote wakeup capable in the
 *						bmAttributes field.
 *					3.  The USB host PC is currently sleeping,
 *						and has previously sent your device a SET
 *						FEATURE setup packet which "armed" the
 *						remote wakeup capability.
 *
 *					This callback should send a RESUME signal that
 *                  has the period of 1-15ms.
 *
 * Note:            Interrupt vs. Polling
 *                  -Primary clock
 *                  -Secondary clock ***** MAKE NOTES ABOUT THIS *******
 *                   > Can switch to primary first by calling USBCBWakeFromSuspend()

 *                  The modifiable section in this routine should be changed
 *                  to meet the application needs. Current implementation
 *                  temporary blocks other functions from executing for a
 *                  period of 1-13 ms depending on the core frequency.
 *
 *                  According to USB 2.0 specification section 7.1.7.7,
 *                  "The remote wakeup device must hold the resume signaling
 *                  for at lest 1 ms but for no more than 15 ms."
 *                  The idea here is to use a delay counter loop, using a
 *                  common value that would work over a wide range of core
 *                  frequencies.
 *                  That value selected is 1800. See table below:
 *                  ==========================================================
 *                  Core Freq(MHz)      MIP         RESUME Signal Period (ms)
 *                  ==========================================================
 *                      48              12          1.05
 *                       4              1           12.6
 *                  ==========================================================
 *                  * These timing could be incorrect when using code
 *                    optimization or extended instruction mode,
 *                    or when having other interrupts enabled.
 *                    Make sure to verify using the MPLAB SIM's Stopwatch
 *                    and verify the actual signal on an oscilloscope.
 *******************************************************************/
void USBCBSendResume( void )
{
    static WORD delay_count;

    USBResumeControl = 1;                // Start RESUME signaling

    delay_count      = 1800U;           // Set RESUME line for 1-13 ms
    do
        delay_count--;
    while ( delay_count );
    USBResumeControl = 0;
}



/*******************************************************************
* Function:        BOOL USER_USB_CALLBACK_EVENT_HANDLER(
*                        USB_EVENT event, void *pdata, WORD size)
*
* PreCondition:    None
*
* Input:           USB_EVENT event - the type of event
*                  void *pdata - pointer to the event data
*                  WORD size - size of the event data
*
* Output:          None
*
* Side Effects:    None
*
* Overview:        This function is called from the USB stack to
*                  notify a user application that a USB event
*                  occured.  This callback is in interrupt context
*                  when the USB_INTERRUPT option is selected.
*
* Note:            None
*******************************************************************/
BOOL USER_USB_CALLBACK_EVENT_HANDLER( USB_EVENT event, void *pdata, WORD size )
{
    switch ( event )
    {
        case EVENT_CONFIGURED:
            USBCBInitEP();
            break;

        case EVENT_SET_DESCRIPTOR:
            USBCBStdSetDscHandler();
            break;

        case EVENT_EP0_REQUEST:
            USBCBCheckOtherReq();
            break;

        case EVENT_SOF:
            USBCB_SOF_Handler();
            break;

        case EVENT_SUSPEND:
            USBCBSuspend();
            break;

        case EVENT_RESUME:
            USBCBWakeFromSuspend();
            break;

        case EVENT_BUS_ERROR:
            USBCBErrorHandler();
            break;

        case EVENT_TRANSFER:
            Nop();
            break;

        default:
            break;
    } /* switch */
    return TRUE;
} /* USER_USB_CALLBACK_EVENT_HANDLER */

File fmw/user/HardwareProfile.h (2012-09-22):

//*********************************************************************
// Copyright (C) 2010 Dave Vanden Bout / XESS Corp. / www.xess.com
//
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
//====================================================================
//
// Module Description:
//  This module maps pins to their functions.  This provides a layer
//  of abstraction.
//
//********************************************************************

#ifndef HARDWAREPROFILE_H
#define HARDWAREPROFILE_H

//Uncomment one of the following lines to make the output HEX of this
//  project work with the HID or Microchip Bootloader
//#define PROGRAMMABLE_WITH_USB_HID_BOOTLOADER
#define PROGRAMMABLE_WITH_USB_MCHPUSB_BOOTLOADER

#define CLOCK_FREQ  48000000           // Clock frequency in Hz.
#define MIPS        12                 // Number of processor instructions per microsecond.

#define PRODUCTION_VERSION

#define INPUT_PIN   1
#define OUTPUT_PIN  0

/** Pin definition macros *******************************************/
#define TRIS( P, B )        ( TRIS ## P ## bits.TRIS ## P ## B )
#define PORT( P, B )        ( PORT ## P ## bits.R ## P ## B )
#define PORT_ASM( P, B )    PORT ## P ##, B, ACCESS
#define LATCH( P, B )       ( LAT ## P ## bits.LAT ## P ## B )
#define LATCH_ASM( P, B )   LAT ## P ##, B, ACCESS

/** Sense presence of external power (not used) *********************/
#if defined( USE_SELF_POWER_SENSE_IO )
#define tris_self_power     TRIS( A, 2 )
#define self_power          PORT( A, 2 )
#else
#define self_power          1
#endif

/** TDO *************************************************************/
#define TDO_PORT        B
#define TDO_BIT         4
#define TDO_MASK        ( 1 << TDO_BIT )
#define TDO_TRIS        TRIS( B, 4 )
#define TDO             PORT( B, 4 )
#define TDO_ASM         PORT_ASM( B, 4 )
#define INIT_TDO()      TDO_TRIS = INPUT_PIN

/** Serial flash disable *******************************************/
#ifdef PRODUCTION_VERSION
#define FLSHDSBL_PORT   B
#define FLSHDSBL_BIT    7
#define FLSHDSBL_MASK   ( 1 << FLSHDSBL_BIT )
#define FLSHDSBL_TRIS   TRIS( B, 7 )
#define FLSHDSBL        PORT( B, 7 )
#define FLSHDSBL_ASM    PORT_ASM( B, 7 )
#define INIT_FLSHDSBL() FLSHDSBL = 1, FLSHDSBL_TRIS = OUTPUT_PIN
#else
#define FLSHDSBL_PORT   B
#define FLSHDSBL_BIT    5
#define FLSHDSBL_MASK   ( 1 << FLSHDSBL_BIT )
#define FLSHDSBL_TRIS   TRIS( B, 5 )
#define FLSHDSBL        PORT( B, 5 )
#define FLSHDSBL_ASM    PORT_ASM( B, 5 )
#define INIT_FLSHDSBL() FLSHDSBL = 1, FLSHDSBL_TRIS = OUTPUT_PIN
#endif

/** Analog I/O 1 pin control ******************************************/
#define ANIO1_PORT      B
#define ANIO1_BIT       5
#define ANIO1_MASK      ( 1 << ANIO1_BIT )
#define ANIO1_TRIS      TRIS( B, 5 )
#define ANIO1           LATCH( B, 5 )
#define ANIO1_ASM       PORT_ASM( B, 5 )
#define INIT_ANIO1()    ANIO1 = 0, ANIO1_TRIS = INPUT_PIN

/** TCK *************************************************************/
#define TCK_PORT        B
#define TCK_BIT         6
#define TCK_MASK        ( 1 << TCK_BIT )
#define TCK_TRIS        TRIS( B, 6 )
#define TCK             LATCH( B, 6 )
#define TCK_ASM         PORT_ASM( B, 6 )
// Disable Port B pullups so they don't interfere with the TCK signal during switchover to MSSP.
#define INIT_TCK()      INTCON2bits.NOT_RABPU = 1, TCK = 0, TCK_TRIS = OUTPUT_PIN

/** FPGA DONE pin***************************************************/
#define DONE_PORT       C
#define DONE_BIT        0
#define DONE_MASK       ( 1 << DONE_BIT )
#define DONE_TRIS       TRIS( C, 0 )
#define DONE            PORT( C, 0 )
#define DONE_ASM        PORT_ASM( C, 0 )
#define INIT_DONE()     DONE_TRIS = INPUT_PIN

/** Sense presence of USB bus (not used) *****************************/
#if defined( USE_USB_BUS_SENSE_IO )
#define tris_usb_bus_sense  TRIS( C, 1 )
#define USB_BUS_SENSE       PORT( C, 1 )
#else
#define USB_BUS_SENSE       1
#endif

/** Analog I/O 0 pin control ******************************************/
#define ANIO0_PORT      C
#define ANIO0_BIT       2
#define ANIO0_MASK      ( 1 << ANIO0_BIT )
#define ANIO0_TRIS      TRIS( C, 2 )
#define ANIO0           LATCH( C, 2 )
#define ANIO0_ASM       PORT_ASM( C, 2 )
#define INIT_ANIO0()    ANIO0 = 0, ANIO0_TRIS = INPUT_PIN

/** FPGA PROG# pin control ******************************************/
#define PROGB_PORT      C
#define PROGB_BIT       3
#define PROGB_MASK      ( 1 << PROGB_BIT )
#define PROGB_TRIS      TRIS( C, 3 )
#define PROGB           LATCH( C, 3 )
#define PROGB_ASM       PORT_ASM( C, 3 )
#define INIT_PROGB()    PROGB = 0, PROGB_TRIS = OUTPUT_PIN
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

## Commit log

2011-10-14 Initial check-in of new XuLA board with Spartan 6 FPGA.
    [XuLA-6SLX.brd, XuLA-6SLX.sch]
2011-10-14 Changed SDRAM to 16Mx16. Removed test points (for now). Updated library parts.
    [XuLA-6SLX.brd, XuLA-6SLX.sch]
2011-10-15 Added micro SD socket. Added full set of control signals to SDRAM.
    [XuLA-6SLX.brd, XuLA-6SLX.sch]
2011-10-16 Arranged components to get SD socket onto board. Made pin assignments between FPGA, SDRAM and proto header.
    [XuLA-6SLX.brd, XuLA-6SLX.sch]
2011-10-21 Routed lots of connections at 5/5 design rules.
    [XuLA-6SLX.brd, XuLA-6SLX.sch]
2011-10-23 Redid routing at 6/6 rules.
    [XuLA-6SLX.brd, XuLA-6SLX.sch]
2011-10-25 Prettied-up the schematic.
    [XuLA-6SLX.sch]
2012-07-15 Renamed PCB files.
    [XuLA2.brd, XuLA2.sch]
2012-07-15 Rotated SD card socket to fit onto board and add space between socket and FPGA.
    [XuLA2.brd, XuLA2.sch]
2012-07-25 Rotated microSD card socket & created manf. array.
    [XuLA2-array.brd, XuLA2.brd, XuLA2.sch]
2012-08-20 Set resistor value in schematic.
    [XuLA2.brd, XuLA2.sch]
2012-10-11 Increased default SPI clock frequency to 25 MHz and fixed "off-by-one" error with clock divider.
2012-12-28 Updated manual to expand explanation of how to use XILINX programming cable with the XuLA2.
2012-12-28 Reduced image size of XuLA2-JTAG-XILINX cable connection.
2012-12-30 Added I2C interface module and its associated HostIo interface.
2013-01-02 Added the ability to read voltages up to 2.048V on the analog I/O pins.
2013-05-10 + Added design for reading/writing the serial configuration flash on the XuLA2 board. + Added SPI interface module. + Added I2C interface module.
2013-10-25 Changed Digikey part# for USB connector.
    [XuLA2.brd, XuLA2.sch]
2013-11-08 Documented rotary encoder module.
2014-02-17 Removed LedDigitsWings since it's more of a StickIt! project. Moved test jigs for HCSR04 ultrasonic sensor and random number generator to their respective library files.
2014-02-17 Added FPGA projects for the XuLA2-LX9 board.
2014-06-24 Added PCB dimensions on text layer 100.
    [XuLA2.brd]
2014-09-16 Updated silkscreen for next fabrication.
    [XuLA2-array.brd]
2014-10-25 Removed old XESS VHDL library for XuLA2 boards.
2014-11-13 Added synthesis configuration files for the -LX9 and -LX25 boards.

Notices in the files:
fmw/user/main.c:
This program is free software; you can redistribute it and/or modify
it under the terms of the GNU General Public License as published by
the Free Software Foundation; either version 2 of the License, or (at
